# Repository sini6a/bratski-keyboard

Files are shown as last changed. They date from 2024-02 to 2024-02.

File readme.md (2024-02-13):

# Bratski Keyboard

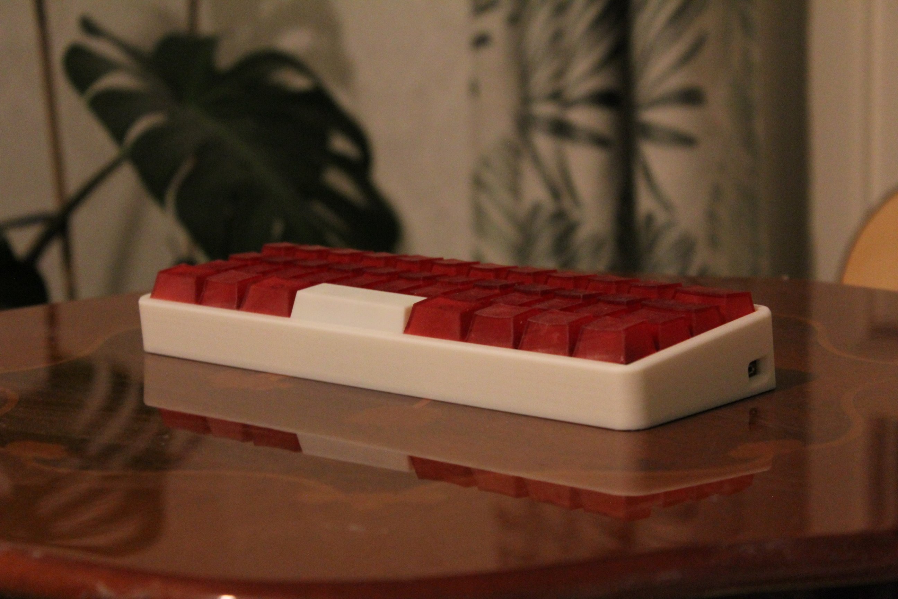
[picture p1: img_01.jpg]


The Bratski Keyboard, named after the Slavic slang term "братски" meaning brother, is a compact mechanical keyboard powered by the Raspberry Pi Pico (RP2040) microcontroller. Designed with 44 soldered keys, it is optimized for seamless use with tablets, laptops, or smartphones. The keyboard boasts MX switches, renowned for their exceptional typing feel and durability, paired with custom resin-printed keycaps, delivering a distinctive and satisfying typing experience. Enhancing the overall robustness, the 3D-printed case, comprised of a main body and a back cover, completes the Bratski Keyboard's durable design.

## Project Structure

The project repository is structured as follows:

-   **`kicad/`**: Contains PCB design files and schematics.
-   **`gerbers/`**: Includes Gerber files essential for manufacturing.
-   **`case/`**: Consists of 3D print files for both the main body and the back cover of the keyboard.
-   **`firmware/`**: Incorporates a modified version of the KMK Firmware with custom key mappings.
-   **`keycaps/`**: MX Keycaps and modified version of the 3u keycap used on the keyboard.

## Pinout and Mapping

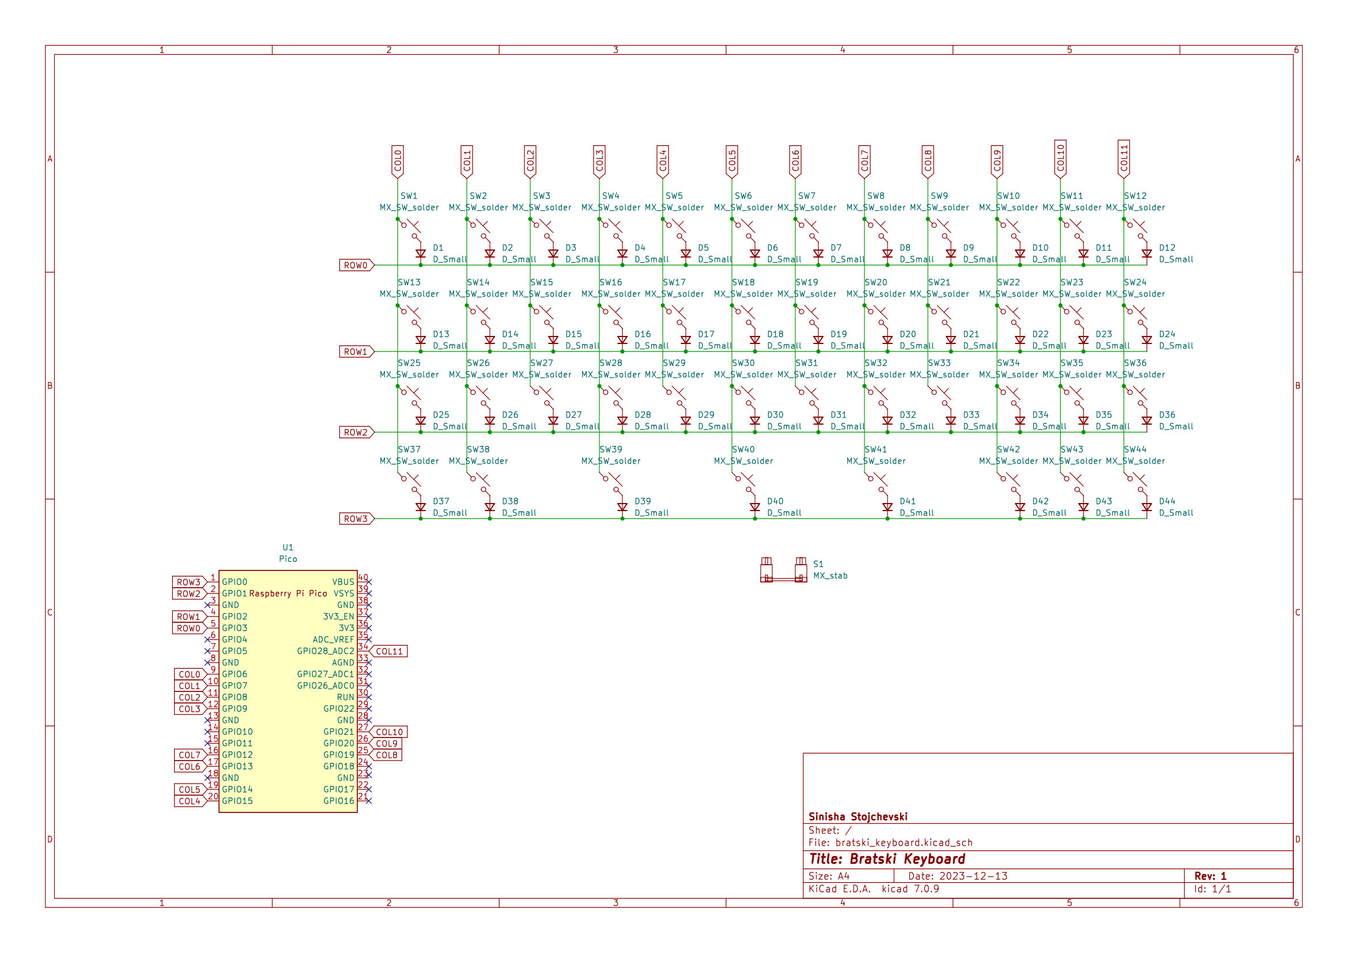
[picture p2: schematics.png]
schematics


## Raspberry Pi Pico Firmware

To enable key mappings on the Raspberry Pi Pico, the Bratski Keyboard employs the KMK firmware. Follow these steps to set it up:

1. Install **[MicroPython](https://www.raspberrypi.com/documentation/microcontrollers/micropython.html)** from the official Raspberry Pi website.
2. Visit the official **[KMK](http://kmkfw.io/)** webpage, download the firmware, customize key mappings as per your preferences and pinouts, and install it on your Raspberry Pi.

_Note:_ If you prefer using the predefined key mappings provided in this repository, you can install the custom firmware available in the firmware folder.

## Keycaps

The Bratski keyboard features keycaps from the **[ConstantinoSchillebeeckx](https://github.com/ConstantinoSchillebeeckx/cherry-mx-keycaps)** collection. These keycaps, crafted using a resin printer, are compatible with MX switches. However, the keyboard supports all MX-compatible keycaps, providing users with flexibility in choosing and customizing their keycap sets.

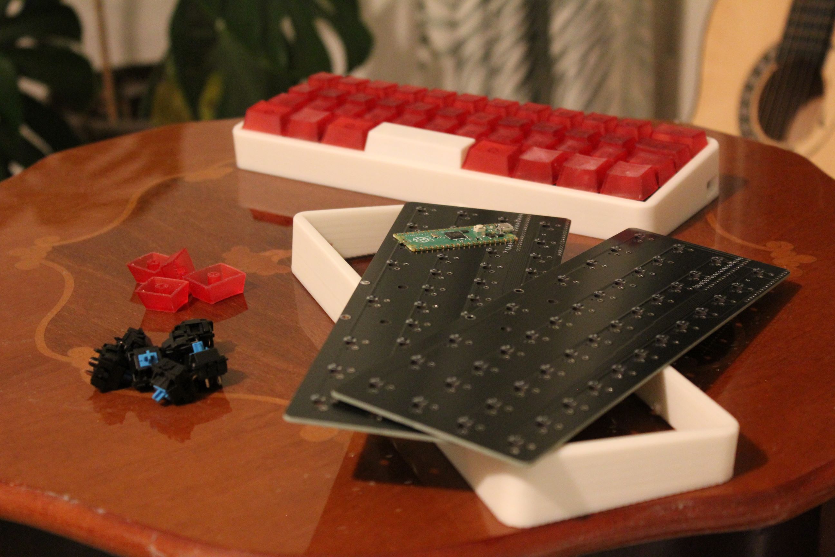
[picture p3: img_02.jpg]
PCB Boards, MX Blue Keycaps, Raspberry Pi Pico

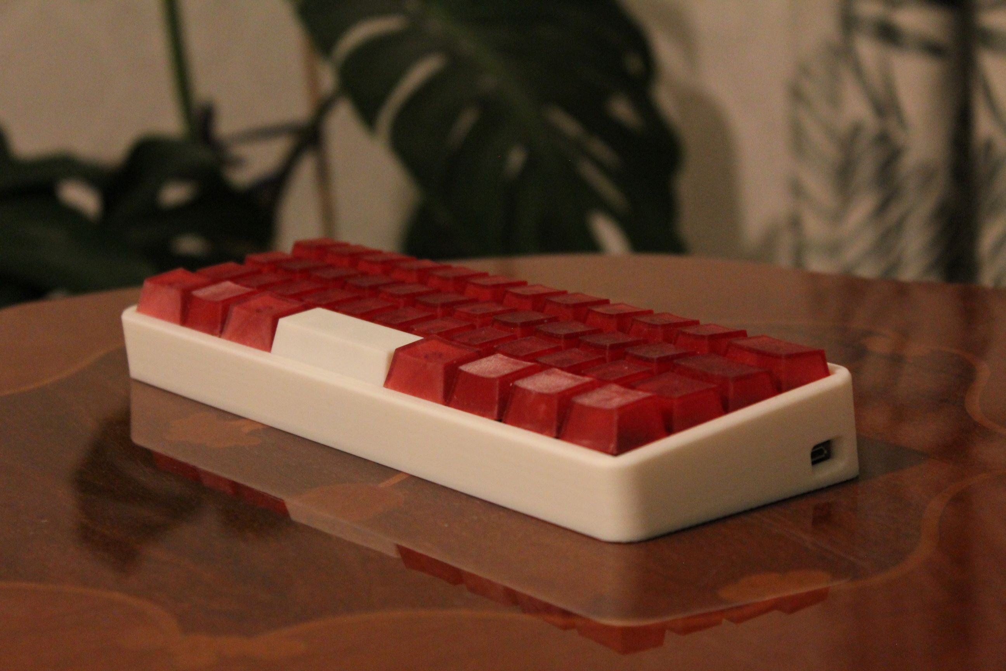
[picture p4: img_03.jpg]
Better look of the keyboard

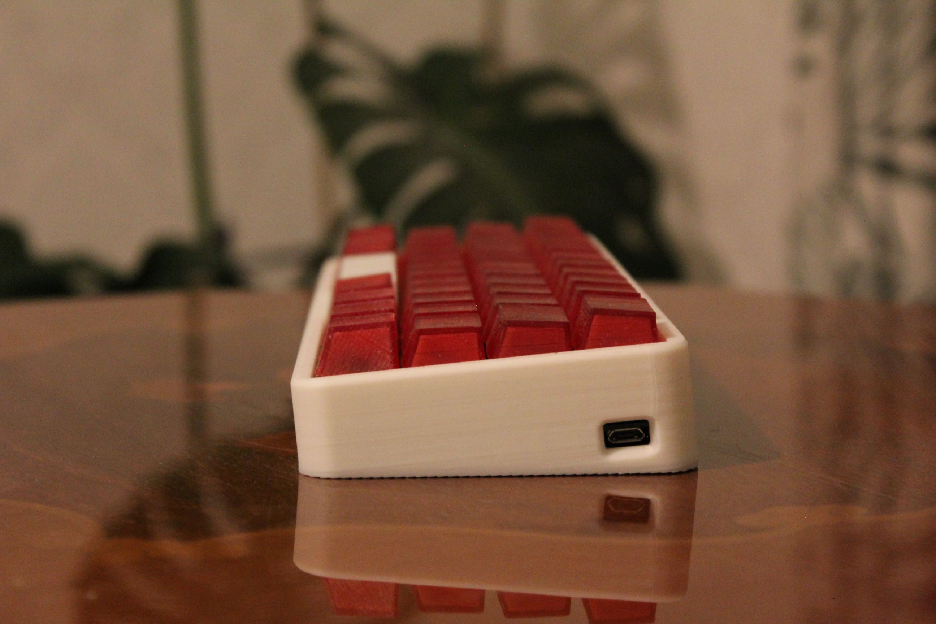
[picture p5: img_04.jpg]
Side image with the connector

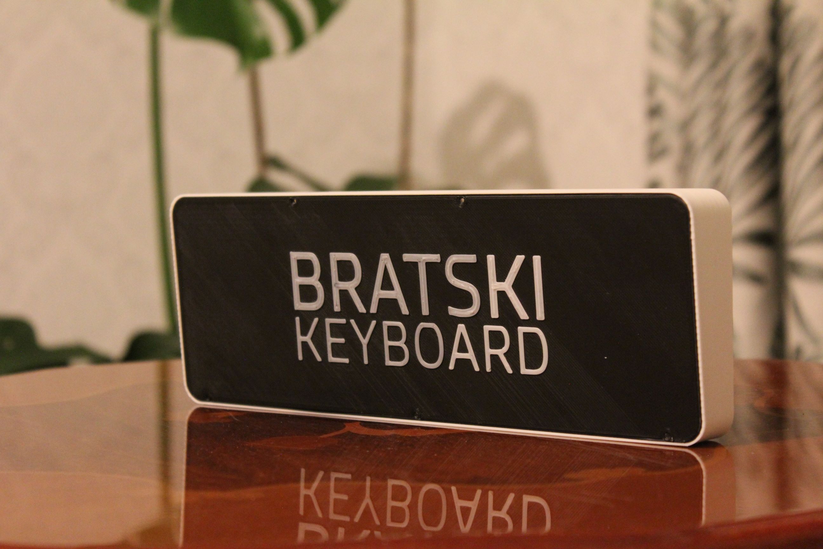
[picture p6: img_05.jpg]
Back of the keyboard


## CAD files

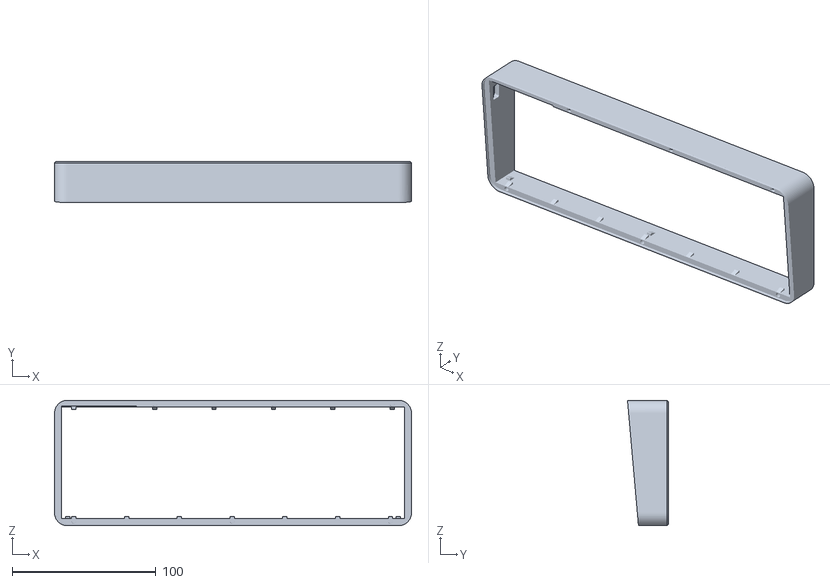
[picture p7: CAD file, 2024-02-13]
case/main_body.stl
248.1 x 28.5 x 87.1

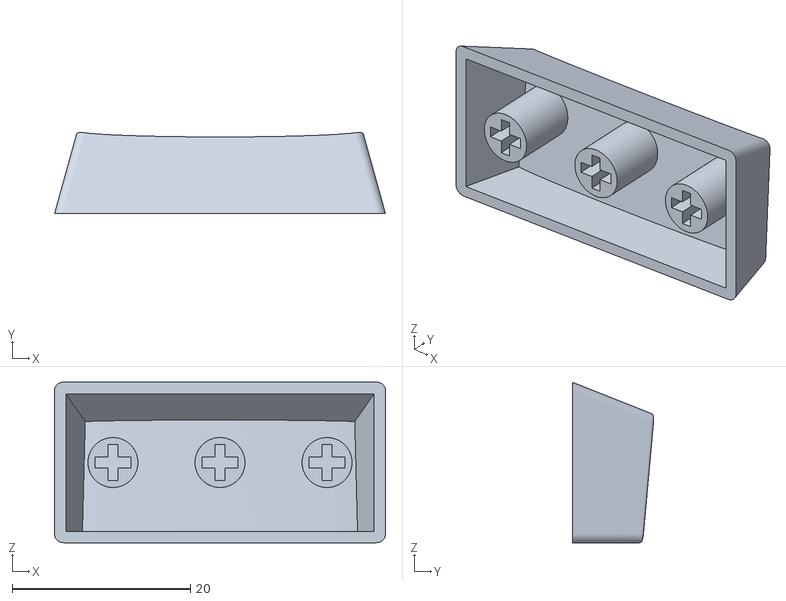
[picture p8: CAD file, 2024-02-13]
keycaps/1x2 R2.stl
37.1 x 9.12 x 18.0

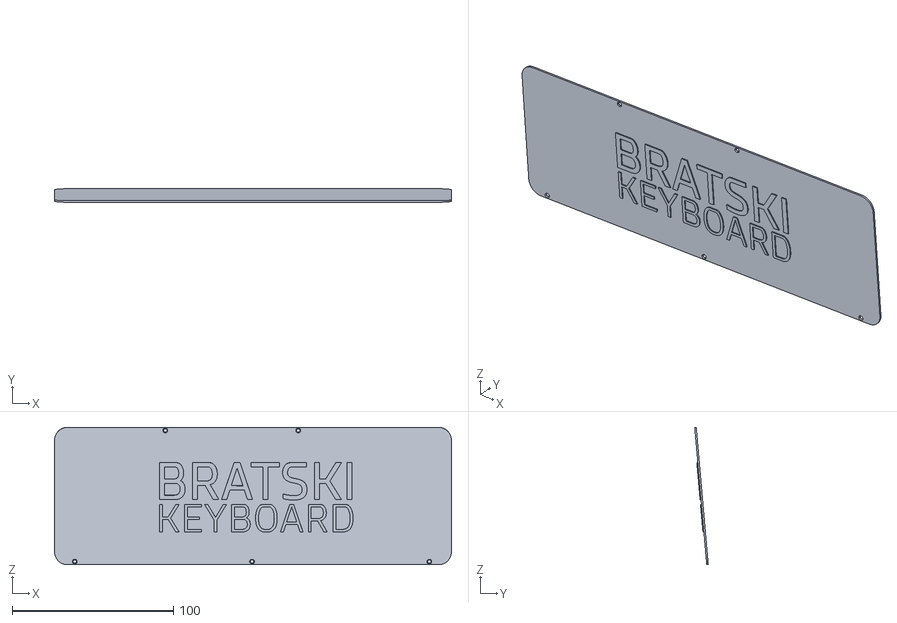
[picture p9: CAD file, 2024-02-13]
case/cover.stl
246.3 x 8.45 x 85.3

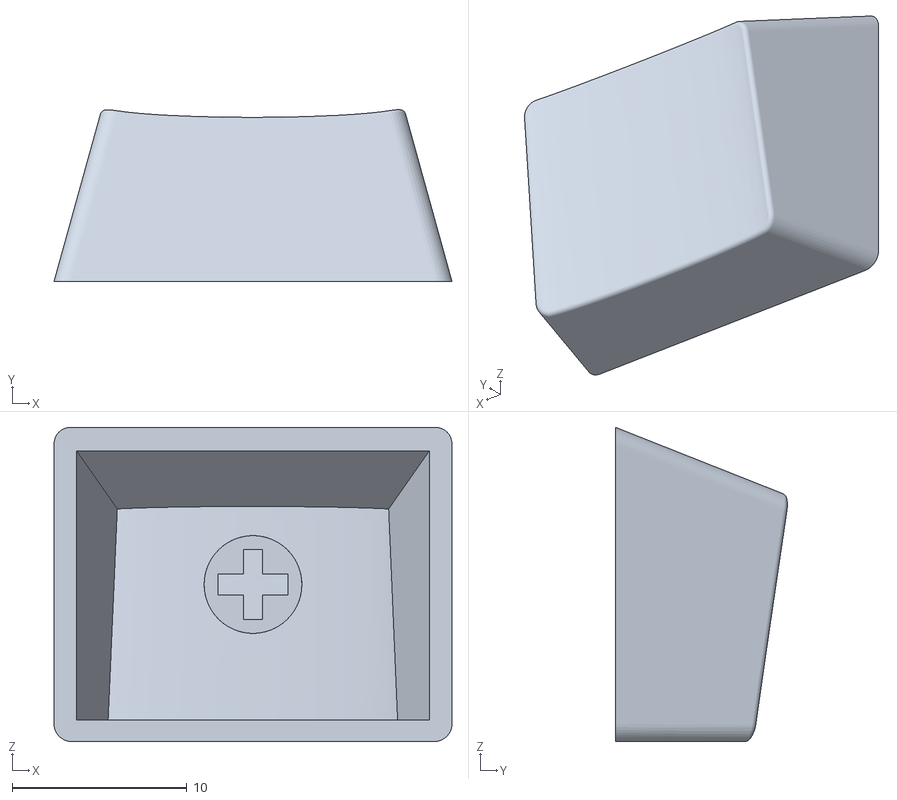
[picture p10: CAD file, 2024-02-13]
keycaps/1x1.25 R1.stl
22.8 x 9.84 x 18.0

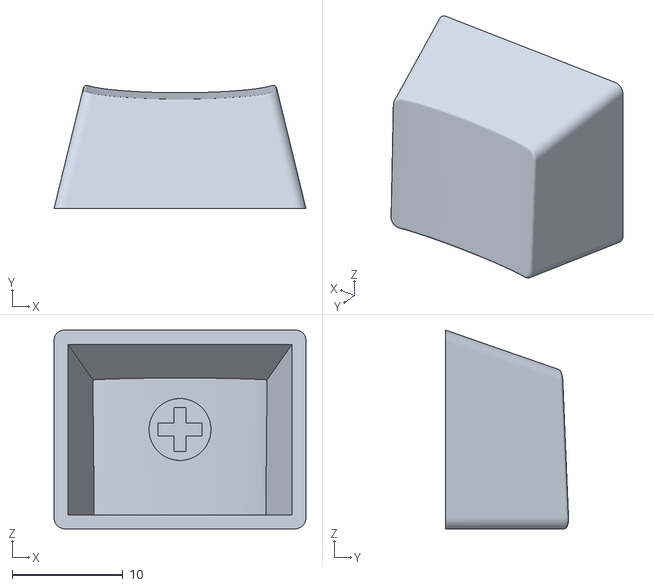
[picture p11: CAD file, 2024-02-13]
keycaps/1x1.25 R4.stl
22.8 x 11.1 x 18.0

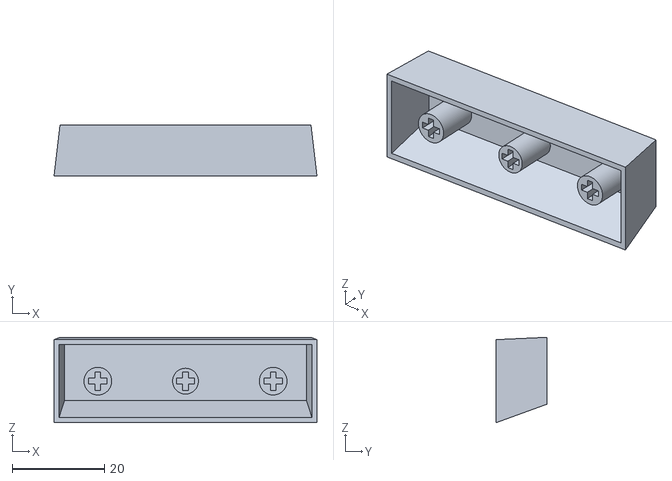
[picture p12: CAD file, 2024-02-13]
keycaps/3u.stl
57.0 x 11.0 x 18.5

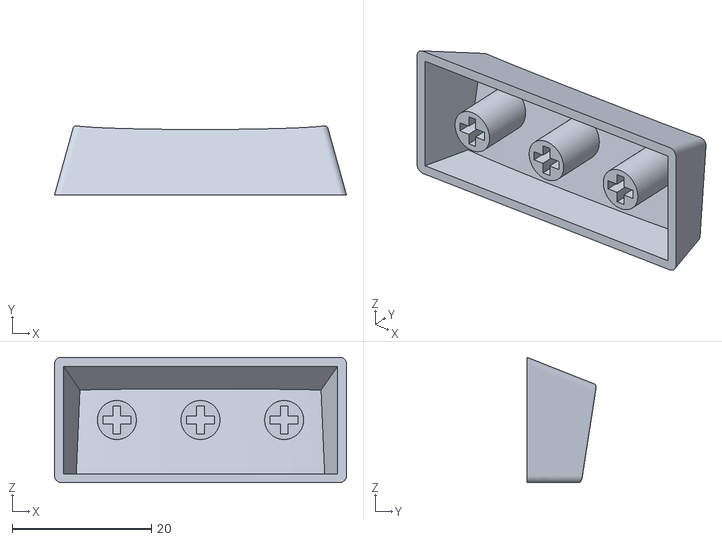
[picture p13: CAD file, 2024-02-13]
keycaps/1x2.25 R1.stl
41.9 x 9.89 x 18.0

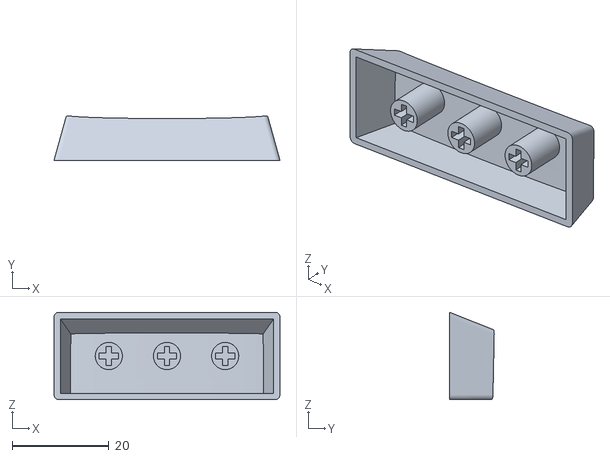
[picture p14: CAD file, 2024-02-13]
keycaps/1x2.5 R3.stl
46.6 x 9.18 x 18.0

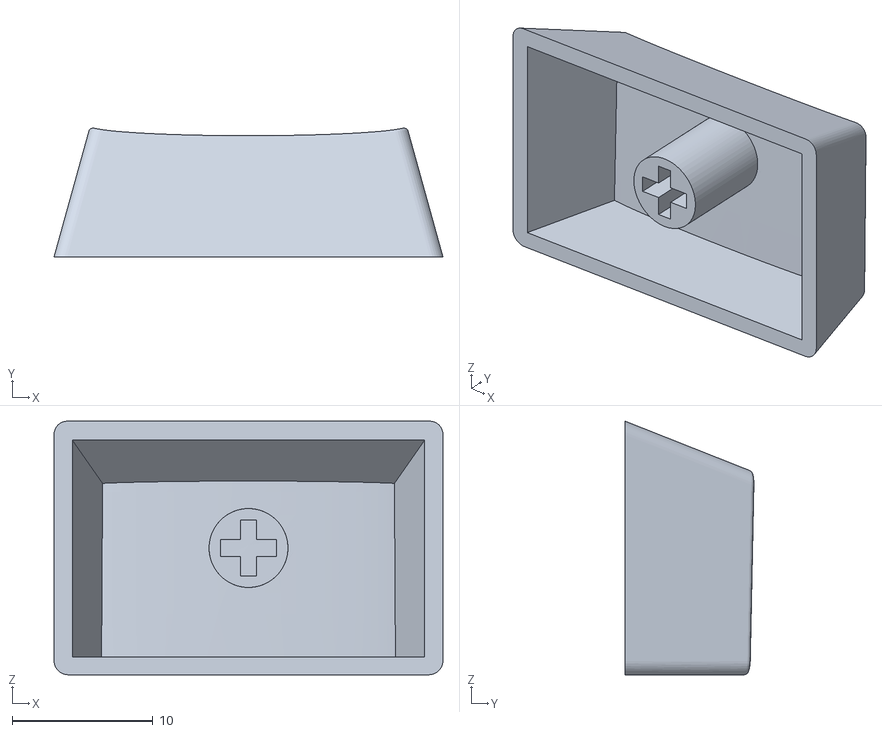
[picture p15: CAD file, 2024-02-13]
keycaps/1x1.5 R3.stl
27.6 x 9.14 x 18.0

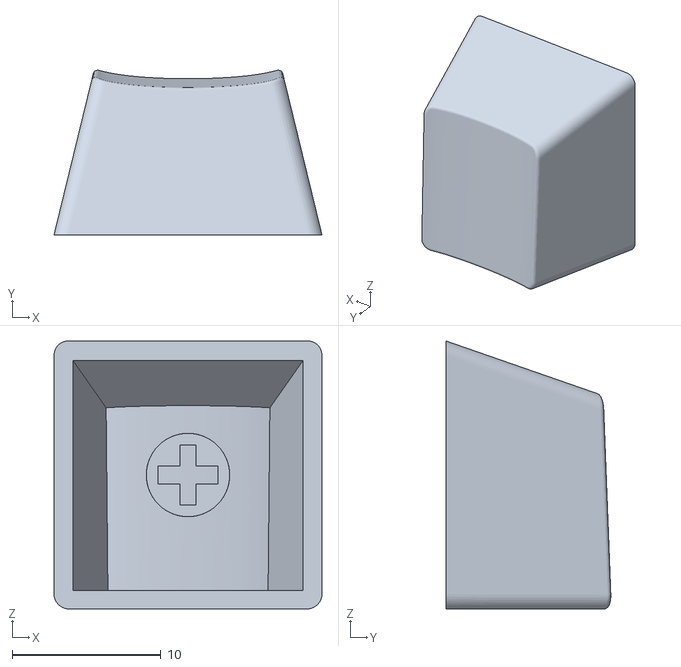
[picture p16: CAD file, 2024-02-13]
keycaps/1x1 R4.stl
18.0 x 11.1 x 18.0

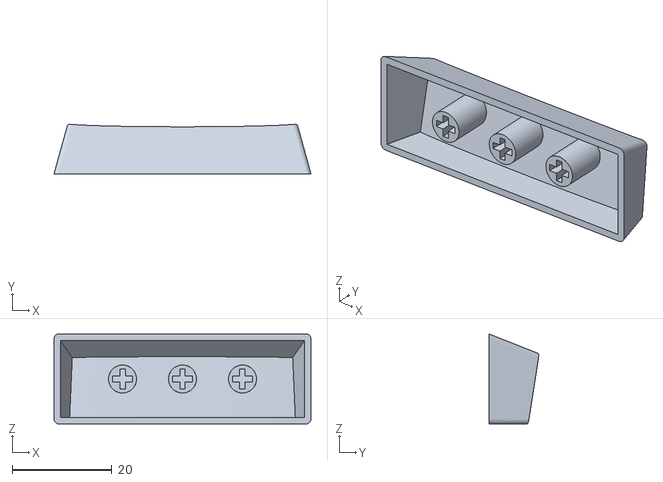
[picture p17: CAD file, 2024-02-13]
keycaps/1x2.75 R1.stl
51.4 x 9.91 x 18.0

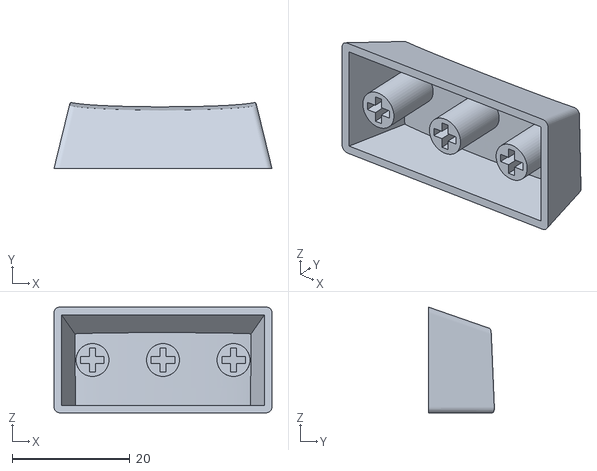
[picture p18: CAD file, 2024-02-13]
keycaps/1x2 R4.stl
37.1 x 11.2 x 18.0

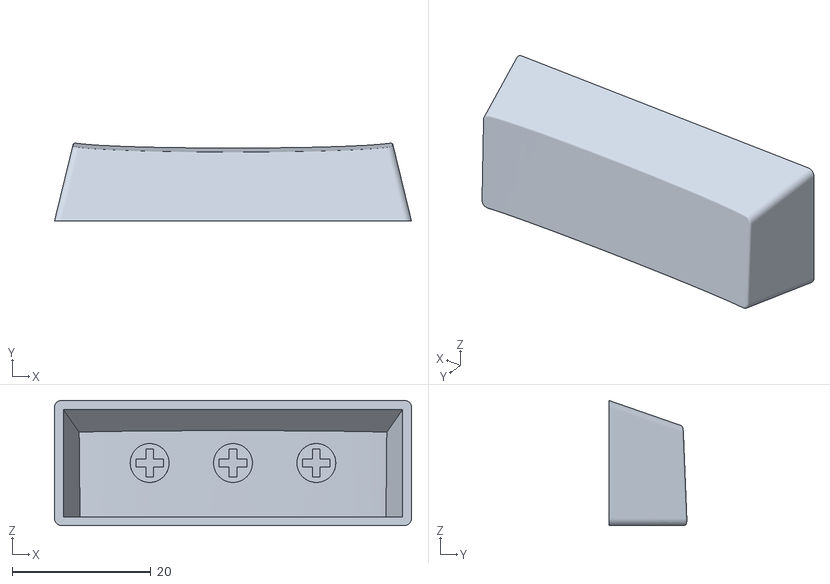
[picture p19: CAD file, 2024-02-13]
keycaps/1x2.75 R4.stl
51.4 x 11.2 x 18.0

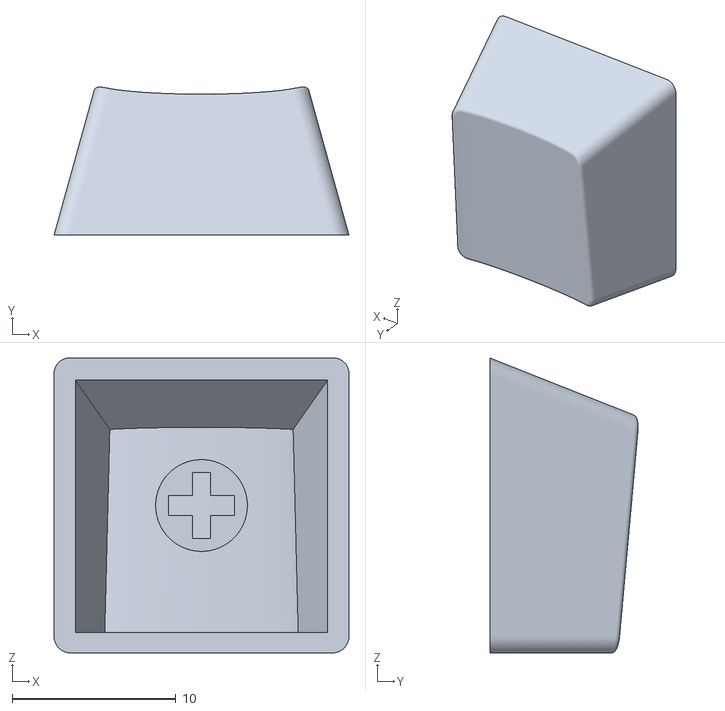
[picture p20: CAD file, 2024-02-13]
keycaps/1x1 R2.stl
18.0 x 9.04 x 18.0

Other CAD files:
keycaps/1x2.75 R2.stl
keycaps/1x2 R1.stl
keycaps/1x1.25 R3.stl
keycaps/1x6.25 R3.stl
keycaps/1x1 R1.stl
keycaps/1x1 R3.stl
keycaps/1x1.25 R2.stl
keycaps/1x1.5 R1.stl
keycaps/1x1.5 R2.stl
keycaps/1x1.5 R4.stl
keycaps/1x1.75 R1.stl
keycaps/1x1.75 R2.stl
keycaps/1x1.75 R3.stl
keycaps/1x1.75 R4.stl
keycaps/1x2 R3.stl
keycaps/1x2.25 R2.stl
keycaps/1x2.25 R3.stl
keycaps/1x2.25 R4.stl
keycaps/1x2.5 R1.stl
keycaps/1x2.5 R2.stl
keycaps/1x2.5 R4.stl
keycaps/1x2.75 R3.stl
keycaps/1x6.25 R1.stl
keycaps/1x6.25 R2.stl
keycaps/1x6.25 R4.stl

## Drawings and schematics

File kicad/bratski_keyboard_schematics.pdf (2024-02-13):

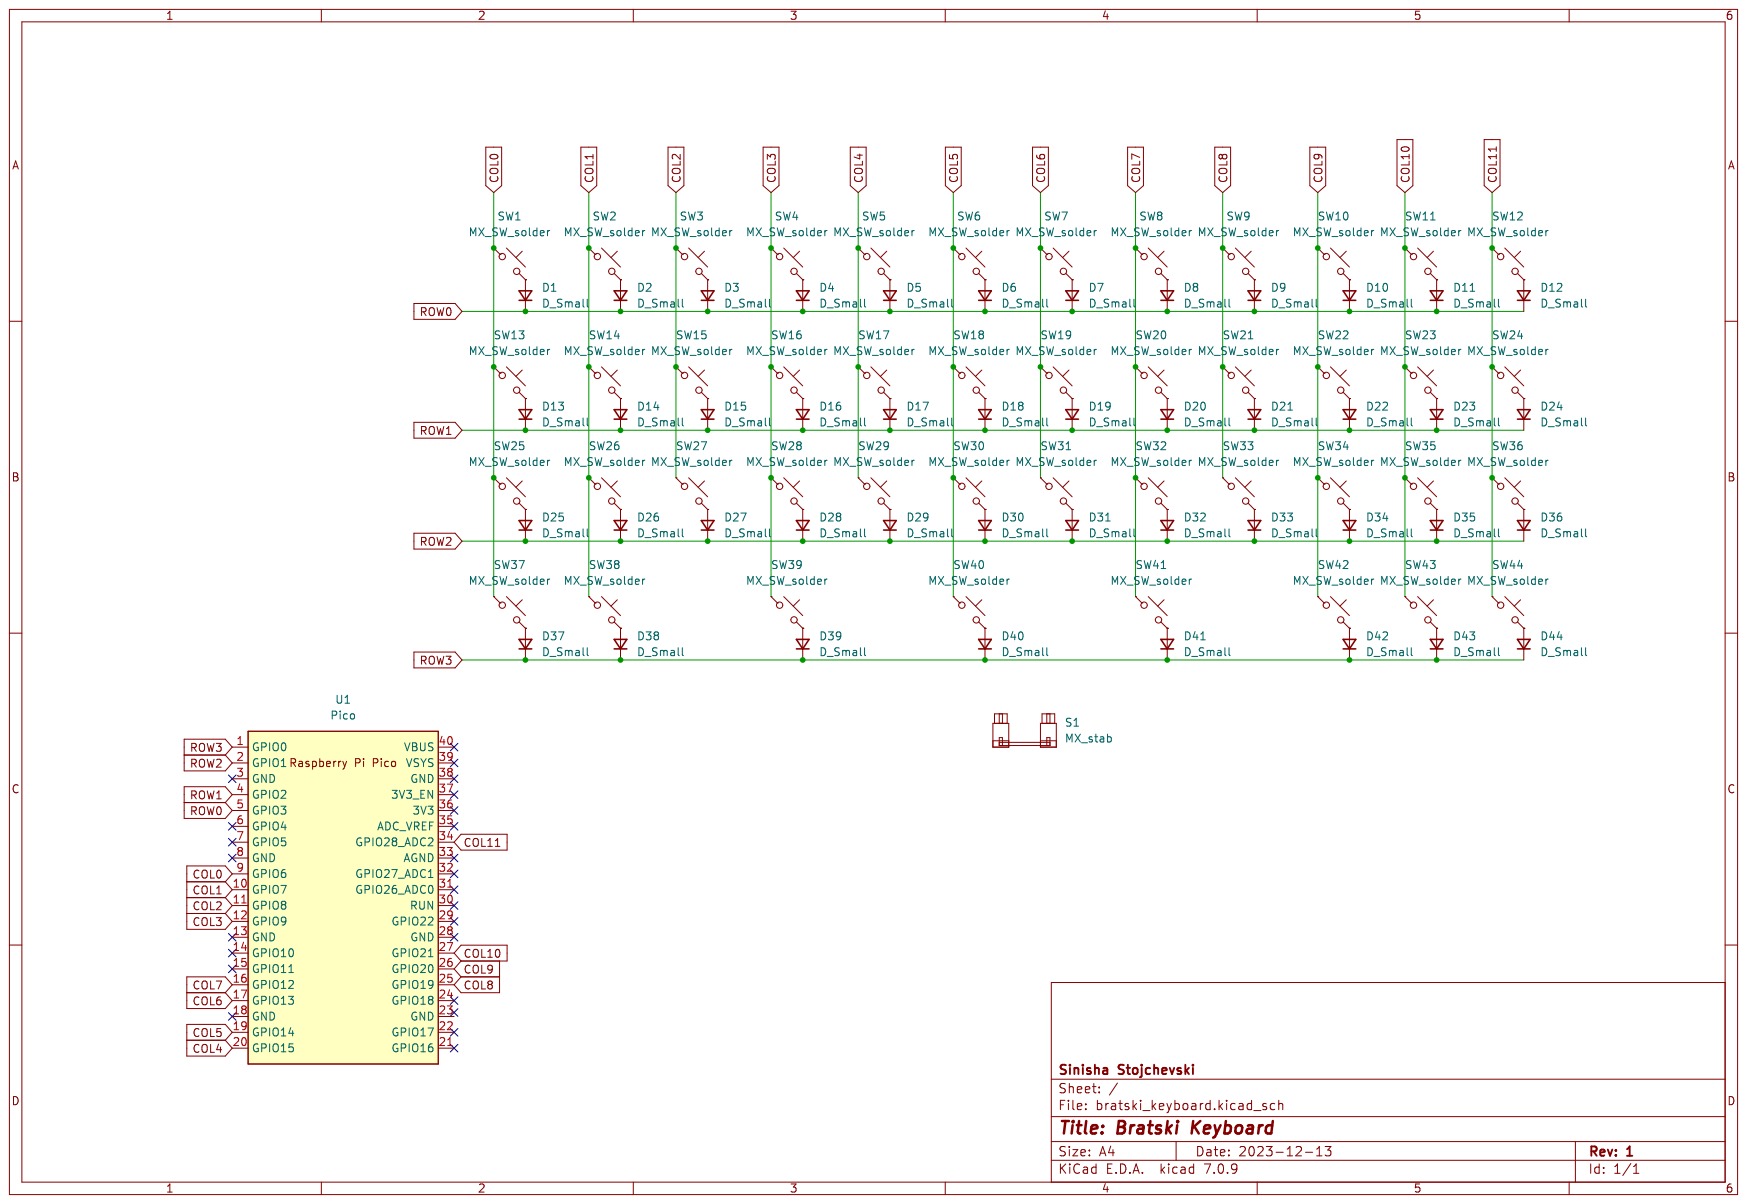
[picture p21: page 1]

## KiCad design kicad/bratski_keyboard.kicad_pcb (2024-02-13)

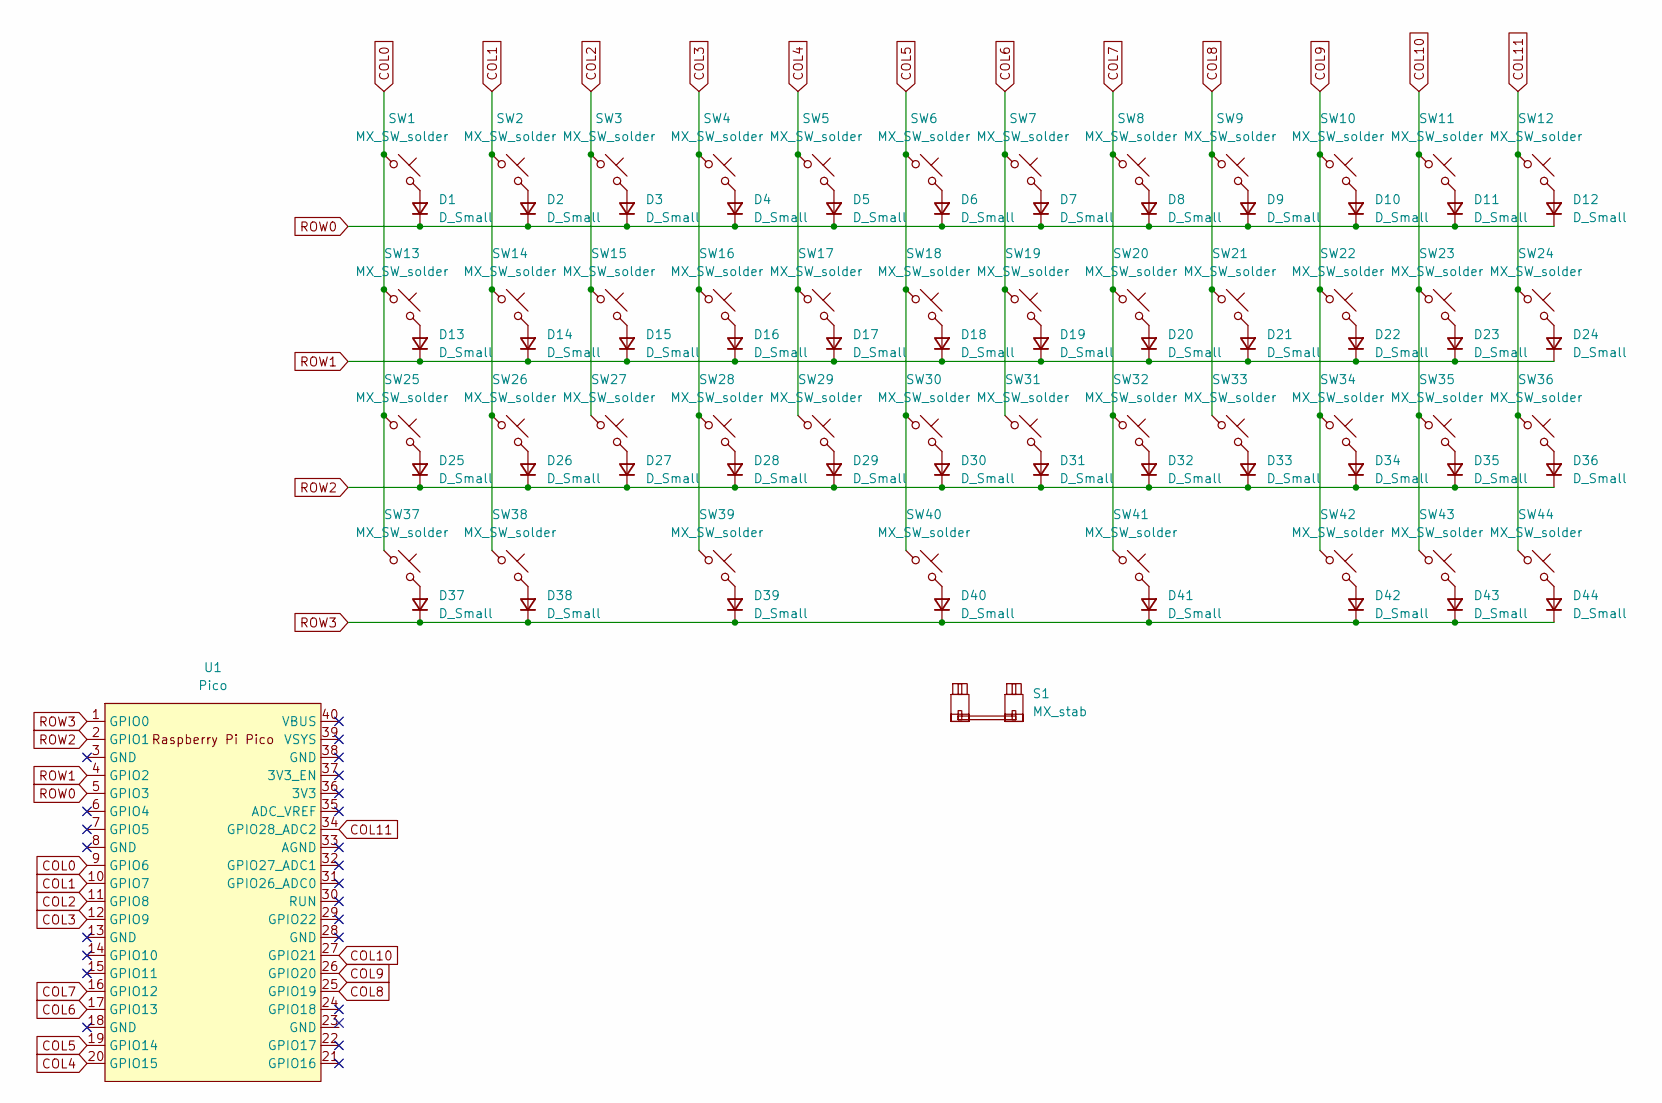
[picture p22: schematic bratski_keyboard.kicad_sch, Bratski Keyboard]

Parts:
D1, D2, D3, D4, D5, D6, D7, D8, D9, D10, D11, D12, D13, D14, D15, D16, D17, D18, D19, D20, D21, D22, D23, D24, D25, D26, D27, D28, D29, D30, D31, D32, D33, D34, D35, D36, D37, D38, D39, D40, D41, D42, D43, D44: D_Small; D_SOD-123
S1: MX_stab; STAB_MX_P_3u
SW1, SW2, SW3, SW4, SW5, SW6, SW7, SW8, SW9, SW10, SW11, SW13, SW14, SW15, SW16, SW17, SW18, SW19, SW20, SW21, SW22, SW23, SW26, SW27, SW28, SW29, SW30, SW31, SW32, SW33, SW34, SW35, SW40: MX_SW_solder; SW_MX_1u
SW12, SW24, SW37, SW39, SW41: MX_SW_solder; SW_MX_1.5u
SW25, SW36, SW38, SW42, SW43, SW44: MX_SW_solder; SW_MX_1.25u
U1: Pico; RPi_Pico_SMD_TH

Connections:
COL0: SW1.1, SW13.1, SW25.1, SW37.1, U1.9 (GPIO6)
COL1: SW2.1, SW14.1, SW26.1, SW38.1, U1.10 (GPIO7)
COL2: SW3.1, SW15.1, SW27.1, U1.11 (GPIO8)
COL3: SW4.1, SW16.1, SW28.1, SW39.1, U1.12 (GPIO9)
COL4: SW5.1, SW17.1, SW29.1, U1.20 (GPIO15)
COL5: SW6.1, SW18.1, SW30.1, SW40.1, U1.19 (GPIO14)
COL6: SW7.1, SW19.1, SW31.1, U1.17 (GPIO13)
COL7: SW8.1, SW20.1, SW32.1, SW41.1, U1.16 (GPIO12)
COL8: SW9.1, SW21.1, SW33.1, U1.25 (GPIO19)
COL9: SW10.1, SW22.1, SW34.1, SW42.1, U1.26 (GPIO20)
COL10: SW11.1, SW23.1, SW35.1, SW43.1, U1.27 (GPIO21)
COL11: SW12.1, SW24.1, SW36.1, SW44.1, U1.34 (GPIO28_ADC2)
unnamed: D1.2 (A), SW1.2
unnamed: D2.2 (A), SW2.2
unnamed: D3.2 (A), SW3.2
unnamed: D4.2 (A), SW4.2
unnamed: D5.2 (A), SW5.2
unnamed: D6.2 (A), SW6.2
unnamed: D7.2 (A), SW7.2
unnamed: D8.2 (A), SW8.2
unnamed: D9.2 (A), SW9.2
unnamed: D10.2 (A), SW10.2
unnamed: D11.2 (A), SW11.2
unnamed: D12.2 (A), SW12.2
unnamed: D13.2 (A), SW13.2
unnamed: D14.2 (A), SW14.2
unnamed: D15.2 (A), SW15.2
unnamed: D16.2 (A), SW16.2
unnamed: D17.2 (A), SW17.2
unnamed: D18.2 (A), SW18.2
unnamed: D19.2 (A), SW19.2
unnamed: D20.2 (A), SW20.2
unnamed: D21.2 (A), SW21.2
unnamed: D22.2 (A), SW22.2
unnamed: D23.2 (A), SW23.2
unnamed: D24.2 (A), SW24.2
unnamed: D25.2 (A), SW25.2
unnamed: D26.2 (A), SW26.2
unnamed: D27.2 (A), SW27.2
unnamed: D28.2 (A), SW28.2
unnamed: D29.2 (A), SW29.2
unnamed: D30.2 (A), SW30.2
unnamed: D31.2 (A), SW31.2
unnamed: D32.2 (A), SW32.2
unnamed: D33.2 (A), SW33.2
unnamed: D34.2 (A), SW34.2
unnamed: D35.2 (A), SW35.2
unnamed: D36.2 (A), SW36.2
unnamed: D37.2 (A), SW37.2
unnamed: D38.2 (A), SW38.2
unnamed: D39.2 (A), SW39.2
unnamed: D40.2 (A), SW40.2
unnamed: D41.2 (A), SW41.2
unnamed: D42.2 (A), SW42.2
unnamed: D43.2 (A), SW43.2
unnamed: D44.2 (A), SW44.2
ROW0: D1.1 (K), D2.1 (K), D3.1 (K), D4.1 (K), D5.1 (K), D6.1 (K), D7.1 (K), D8.1 (K), D9.1 (K), D10.1 (K), D11.1 (K), D12.1 (K), U1.5 (GPIO3)
ROW1: D13.1 (K), D14.1 (K), D15.1 (K), D16.1 (K), D17.1 (K), D18.1 (K), D19.1 (K), D20.1 (K), D21.1 (K), D22.1 (K), D23.1 (K), D24.1 (K), U1.4 (GPIO2)
ROW2: D25.1 (K), D26.1 (K), D27.1 (K), D28.1 (K), D29.1 (K), D30.1 (K), D31.1 (K), D32.1 (K), D33.1 (K), D34.1 (K), D35.1 (K), D36.1 (K), U1.2 (GPIO1)
ROW3: D37.1 (K), D38.1 (K), D39.1 (K), D40.1 (K), D41.1 (K), D42.1 (K), D43.1 (K), D44.1 (K), U1.1 (GPIO0)

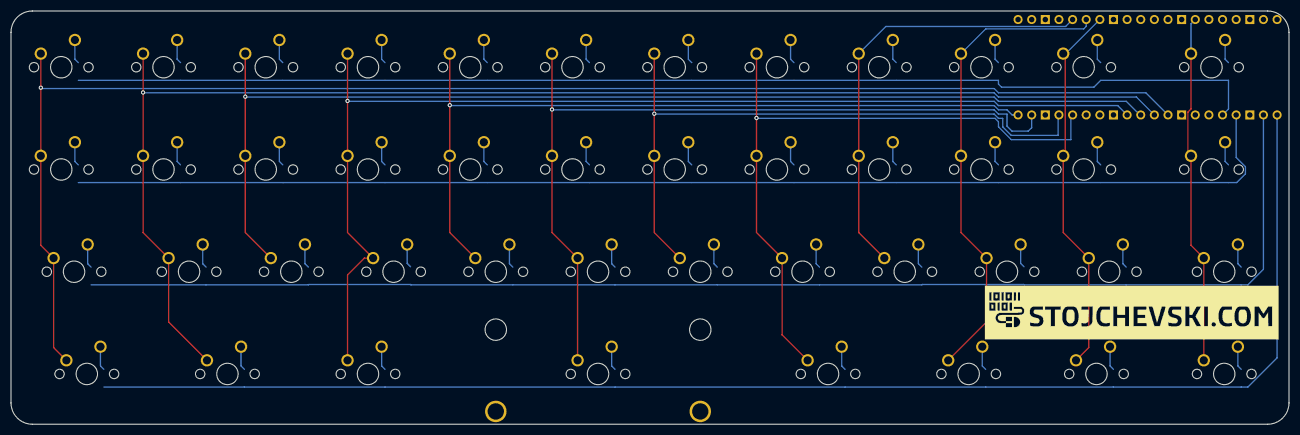
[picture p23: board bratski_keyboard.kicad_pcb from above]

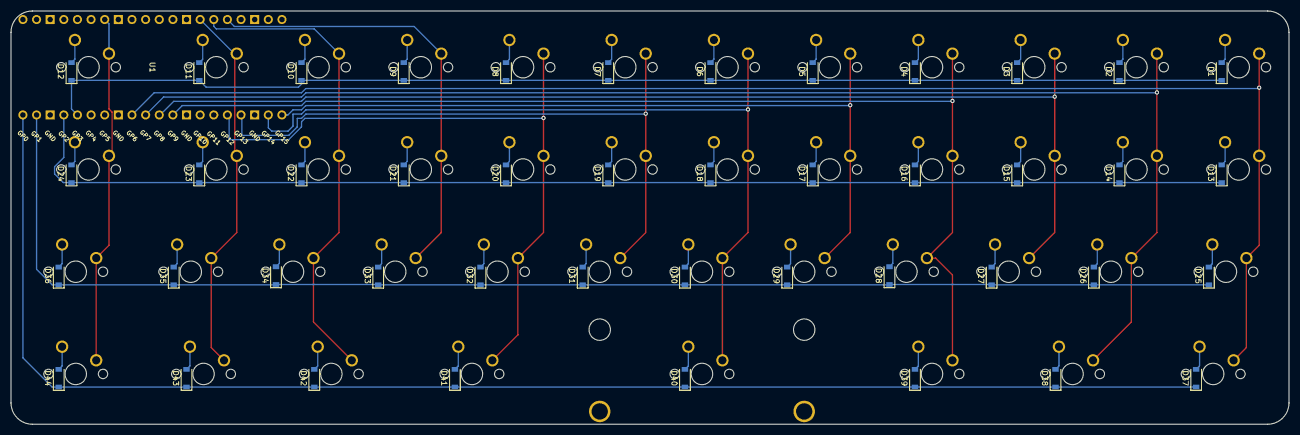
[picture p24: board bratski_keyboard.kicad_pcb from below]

Board: 2 copper layers, 238.1 x 77.0 mm, 90 parts (45 on the bottom side), 60 nets.

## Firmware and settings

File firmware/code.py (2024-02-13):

import board

from kmk.kmk_keyboard import KMKKeyboard
from kmk.keys import KC
from kmk.scanners import DiodeOrientation
from kmk.modules.layers import Layers
from kmk.modules.tapdance import TapDance

print("Starting")

keyboard = KMKKeyboard()
keyboard.modules.append(Layers())
tapdance = TapDance()
tapdance.tap_time = 65
keyboard.modules.append(tapdance)


keyboard.col_pins = (board.GP6,
                     board.GP7,
                     board.GP8,
                     board.GP9,
                     board.GP15,
                     board.GP14,
                     board.GP13,
                     board.GP12,
                     board.GP19,
                     board.GP20,
                     board.GP21,
                     board.GP28)
keyboard.row_pins = (board.GP3,
                     board.GP2,
                     board.GP1,
                     board.GP0)
keyboard.diode_orientation = DiodeOrientation.COL2ROW

keyboard.keymap = [
    [
        KC.NO, KC.Q, KC.W,KC.E,KC.R,KC.T,KC.Y,KC.U,KC.I,KC.O,KC.P,KC.BKDL,
        KC.TAB, KC.A,KC.S,KC.D,KC.F,KC.G,KC.H,KC.J,KC.K,KC.L,KC.SCLN, KC.ENTER,
        KC.LSFT, KC.Z,KC.X,KC.C,KC.V,KC.B,KC.N,KC.M,KC.COMM,KC.DOT,KC.SLSH,KC.RSFT,
        KC.LCTL,KC.LGUI,KC.NO,KC.MO(1),KC.NO,KC.SPACE,KC.NO,KC.RALT,KC.NO,KC.FN,KC.RCTL,
     ],
     [
        KC.ESC,KC.N1,KC.N2,KC.N3,KC.N4,KC.N5,KC.N6,KC.N7,KC.N8,KC.N9,KC.N0,KC.BKDL,
        KC.NO,KC.F1,KC.F2,KC.F3,KC.F4,KC.F5,KC.F6,KC.F7,KC.F8,KC.F9,KC.F10,KC.NO,
        KC.NO,KC.NO,KC.NO,KC.NO,KC.NO,KC.NO,KC.NO,KC.NO,KC.NO,KC.NO,KC.NO,KC.NO,
        KC.NO,KC.LGUI,KC.NO,KC.NO,KC.NO,KC.NO,KC.NO,KC.LEFT,KC.NO,KC.UP,KC.DOWN,KC.RIGHT,
     ],
]

#,KC.LBRC
#KC.QUOT,

if __name__ == '__main__':
    keyboard.go()
